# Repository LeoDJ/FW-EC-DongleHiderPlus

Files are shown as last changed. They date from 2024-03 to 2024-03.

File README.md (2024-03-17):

# DongleHider+ Framework Laptop Expansion Card

Want to use a Logitech Unifying Dongle (or similar) without having a dongle permanently sticking out and giving up on a precious expansion card slot?  

Now there's the `DongleHider+`!  

Simply (permanently) mount the dongle inside the card and still have an USB A port available!  

There even is room and solder pads for 1-2 additional dongles. Your imagination (and physics) are the only limits!

See also the [thread on Mastodon about the build process etc](https://chaos.social/@LeoDJ/112040053271880119).

<p float="left" style="display: flex; flex-wrap: wrap; align-items: center;">
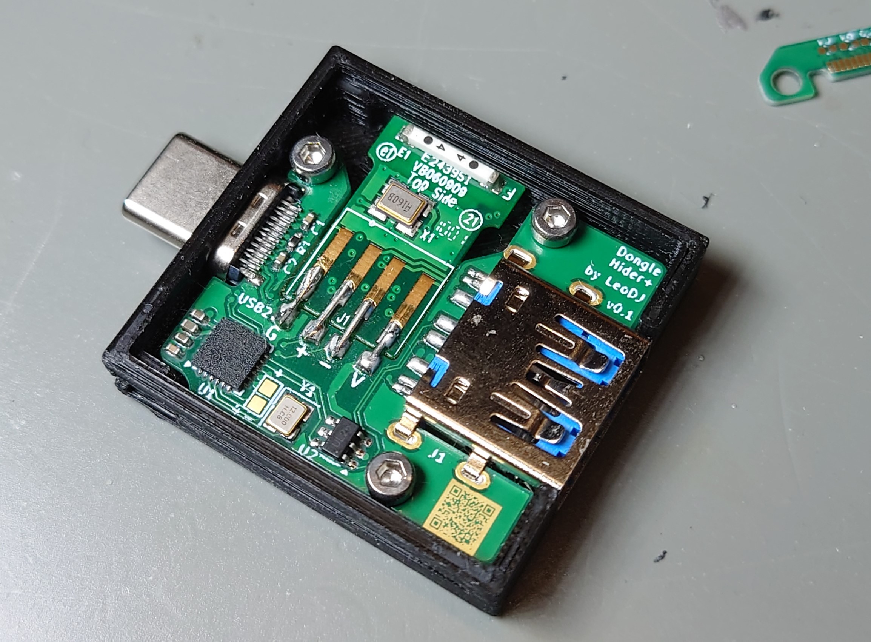
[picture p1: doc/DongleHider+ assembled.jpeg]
  &nbsp;
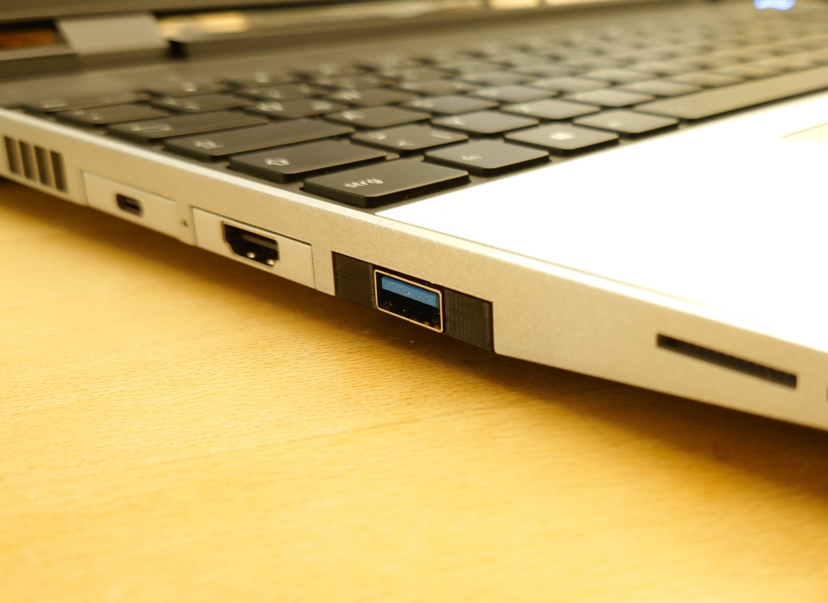
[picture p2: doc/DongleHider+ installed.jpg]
  
</p>

## Compatibility Notes

The expansion card was only tested on **Windows** and **AMD** Framework **13 and 16** laptops as of right now. There the following behaviour has been observed:
- With only a dongle active, the CH334 hub IC draws around 20mA. (In addition to the ~25mA of the Unifying dongle)
  - When nothing is connected to the hub, it goes to sleep and draws <1mA. (But this is seldomly the case with a dongle permanently attached to it :P )
- Despite earlier fears, the USB 3 "route-around-2.0-hub" topology doesn't seem to cause problems in the wild, except:
- When connected to a **USB4 capable expansion card slot** and an external **USB 3 device** is plugged in, the **internal dongle stops working**, but is still displayed as connected in Windows.
  - As soon as the USB 3 device gets unplugged, the internal dongle immediately begins to work again (probably without a re-enumeration).
  - USB 2 devices seem to work without a problem for the most part, although one of the tested USB thumb drives took a few re-plugs until it enumerated.
  - This behaviour is not seen on the other non-USB4-capable expansion card slots, there USB 3 devices work great alongside the internal dongle

It's currently unclear what the behaviour would be under Linux or on Intel laptops. <sup>[You can help expand this]</sup>

### Dongles

This project was aimed first and foremost at Logitech Unifying dongles. But you can check if your dongle would fit by disassembling it and checking its size against the CAD model (linked below).  
Keep in mind that there is more room under / above the PCB too. (I just made the cutout so a Unifying dongle PCB would fit neat-ish)

The Unifying dongles can be disassembled pretty easily:
|||
|---|---|
|  | **Gen 1:** <br>Carefully break off the plastic from the metal part using a pair of pliers. <br>(Can be glued back together, if needed)|
|  | **Gen 2:** <br>Slide flat screwdriver (or similar) between the metal and the orange plastic of the front of the USB a plug and carefully pry open the metal shell until it slides off. <br>[Youtube video](https://www.youtube.com/watch?v=NB5uVCrXxT8) |

## PCB
- [View the latest schematic and board view](https://kicanvas.org/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) thanks to KiCanvas.
- [Interactive HTML BOM](https://leodj.github.io/FW-EC-DongleHiderPlus/DongleHiderPlus_PCB/DongleHiderPlus_PCB.ibom.html)
- I've ordered the PCB and assembled it myself, but it should be able to be mostly assembled by PCBA services (like JLCPCB) too. The Gerber/BOM/CPL files are provided in the [PCB/jlcpcb/production_files/](DongleHiderPlus_PCB/jlcpcb/production_files/) folder.

<p float="left" style="display: flex; flex-wrap: wrap; align-items: center;">
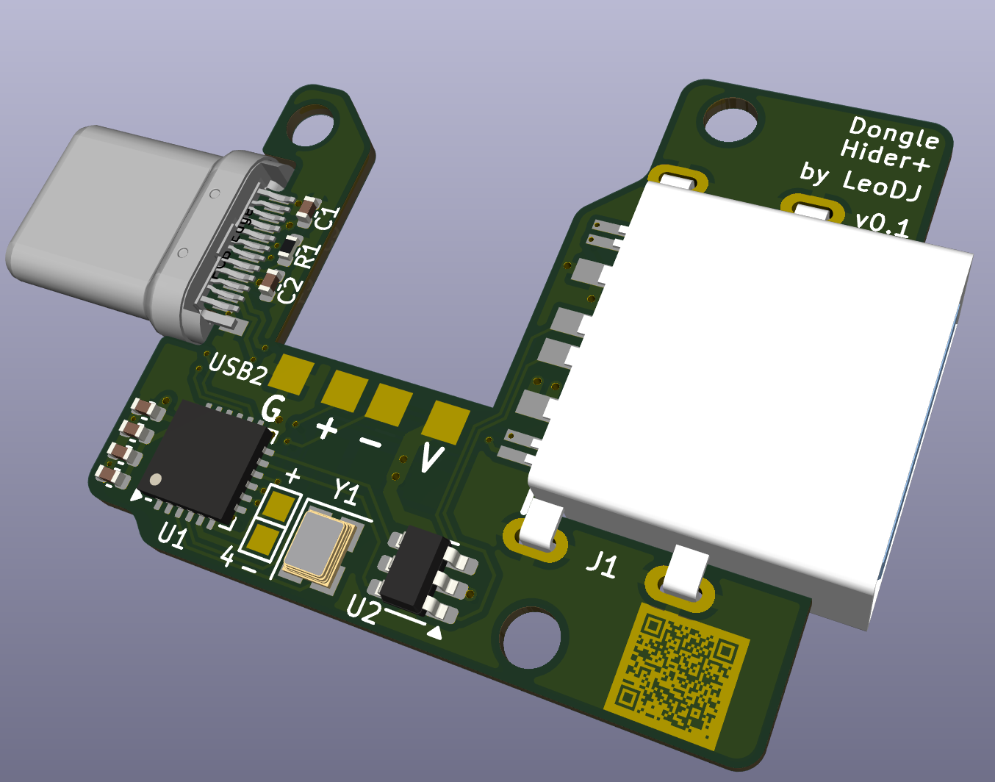
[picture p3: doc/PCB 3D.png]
  &nbsp;
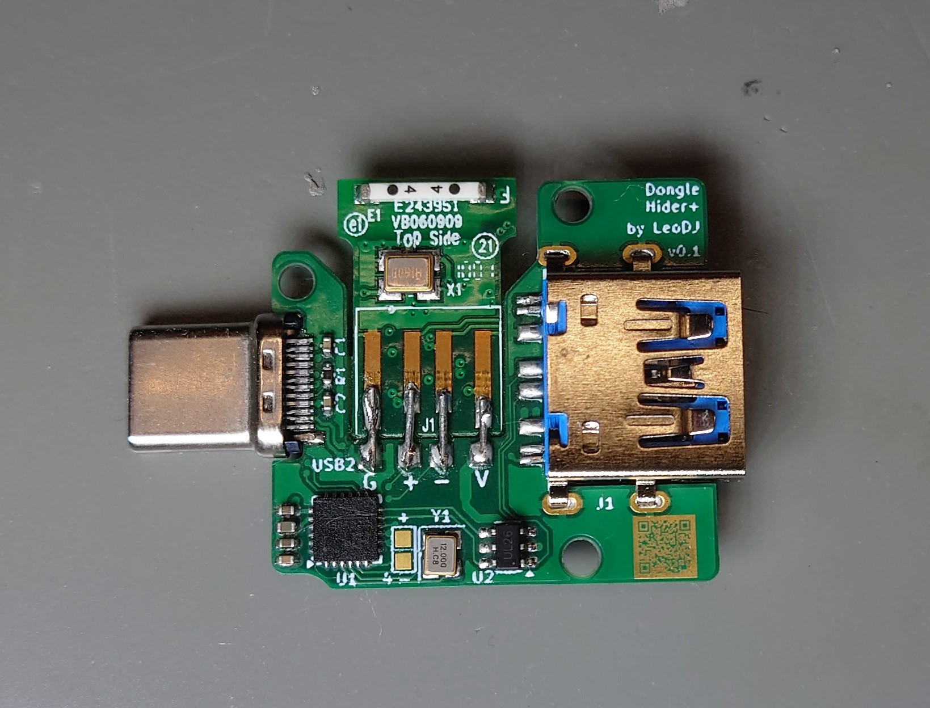
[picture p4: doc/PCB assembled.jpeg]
  
</p>

## Mechanical Design

- The [CAD model](https://cad.onshape.com/documents/ed6483270486e65268e8fd84/w/d29ba2284b9bcf206122f777/e/2459b9ec86bce6d6c9526a6b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) for the shell etc. was done in OnShape.
- The PCB is fastened to the case using 3 M2x3 self-tapping screws
- Simply print the .step file from the [Mechanical/](Mechanical/DongleHiderPlus_Shell.step) folder. I printed it lying down with 0.1mm layer height and supports (for the lip on the bottom). But standing vertically (on the USB-C hole side) should work too.

<p float="left" style="display: flex; flex-wrap: wrap; align-items: center;">
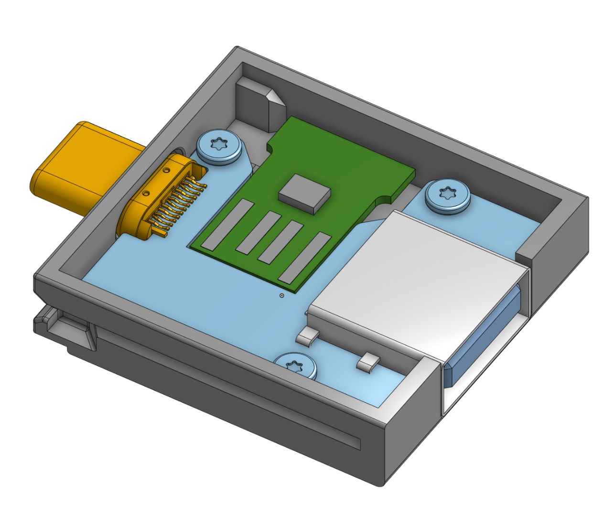
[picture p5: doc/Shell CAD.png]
  
</p>

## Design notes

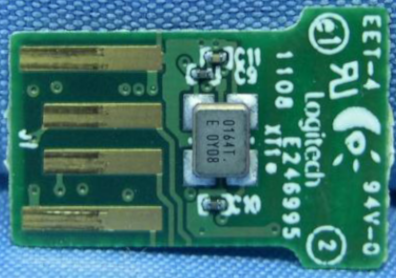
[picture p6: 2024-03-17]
doc/Unifying_PCB_top.png

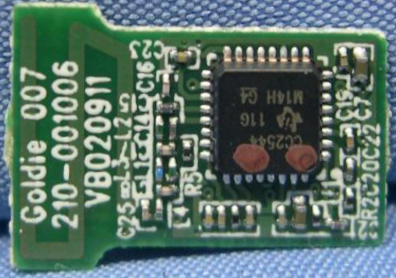
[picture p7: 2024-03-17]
doc/Unifying_PCB_bot.png

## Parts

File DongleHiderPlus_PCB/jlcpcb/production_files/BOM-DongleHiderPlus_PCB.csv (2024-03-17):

Comment | Designator | Footprint | LCSC
10n | C1,C2,C3,C4 | C_0402_1005Metric | C15195
10u | C7 | C_0402_1005Metric | C15525
5k1 | R1 | R_0402_1005Metric | C25905
USBLC6-2SC6 | U2 | SOT-23-6 | C2827654
12MHz | Y1 | Crystal_SMD_2520-4Pin_2.5x2.0mm | C284156
100n | C6 | C_0402_1005Metric | C307331
CH334F | U1 | QFN-24-1EP_4x4mm_P0.5mm_EP2.7x2.7mm | C5187527
1u | C5,C8 | C_0402_1005Metric | C52923
USB_C_Plug | P1 | USB_C_Plug_Molex_105444 | C561769
USB3_A | J1 | USB-A-SMD_HC-USB3.0-C345-P | C7501863

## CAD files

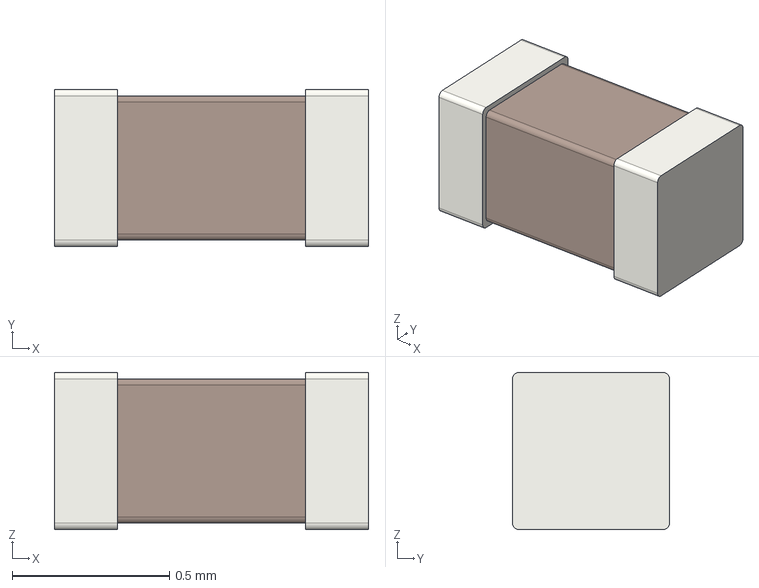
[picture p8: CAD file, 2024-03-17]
DongleHiderPlus_PCB/3dshapes/C_0402_1005Metric.step
1.00 x 0.5 x 0.5 mm

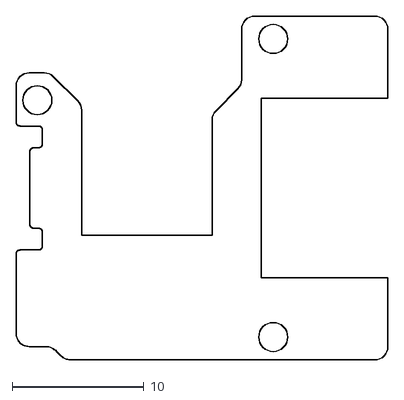
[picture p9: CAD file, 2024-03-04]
Mechanical/PCB Outline.dxf
28.2 x 26.1

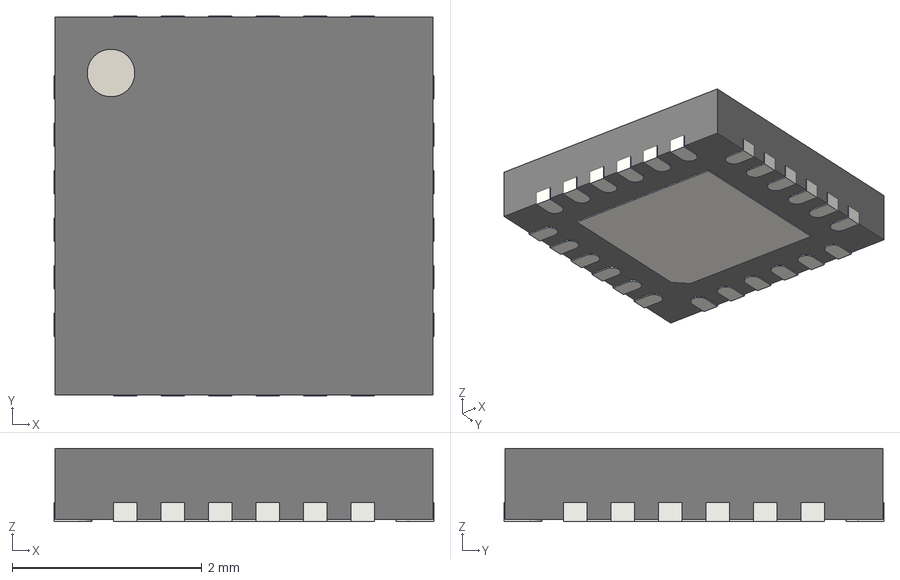
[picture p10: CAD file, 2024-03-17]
DongleHiderPlus_PCB/3dshapes/QFN-24-1EP_4x4mm_P0.5mm_EP2.6x2.6mm.step
4.00 x 4.00 x 0.77 mm

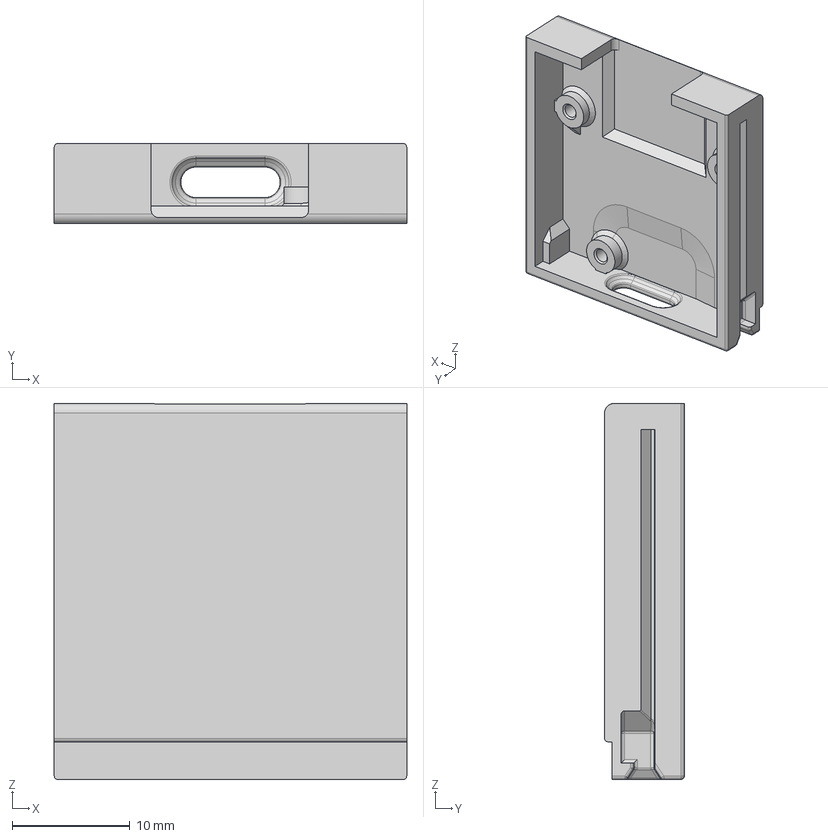
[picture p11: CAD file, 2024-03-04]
Mechanical/DongleHiderPlus_Shell.step
30.0 x 6.80 x 32.0 mm

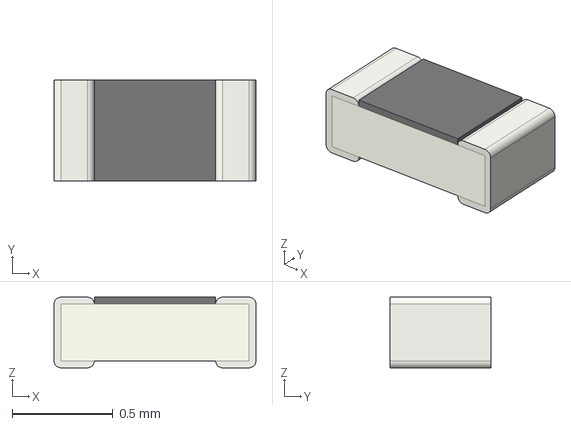
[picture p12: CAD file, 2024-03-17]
DongleHiderPlus_PCB/3dshapes/R_0402_1005Metric.step
1.00 x 0.5 x 0.35 mm

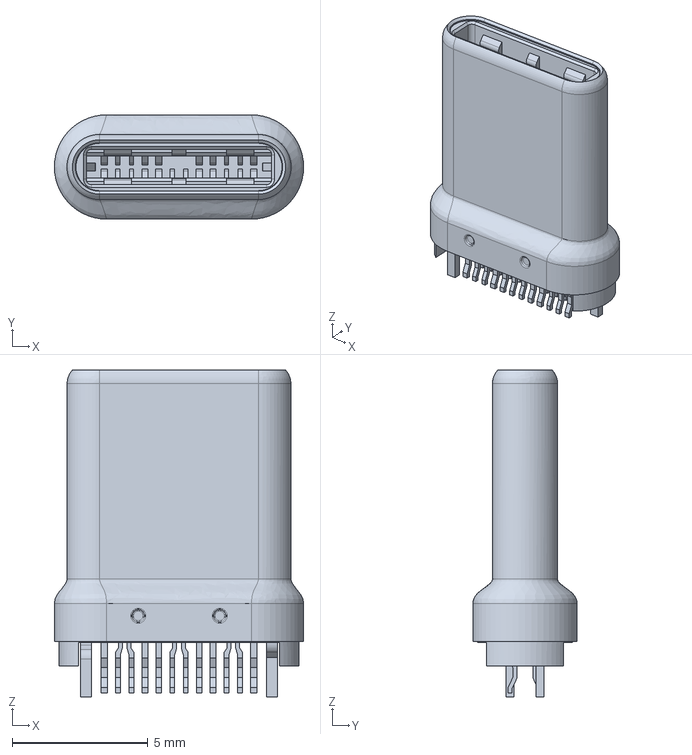
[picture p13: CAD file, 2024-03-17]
DongleHiderPlus_PCB/3dshapes/Molex_1054440011.stp
9.18 x 3.84 x 12.0 mm

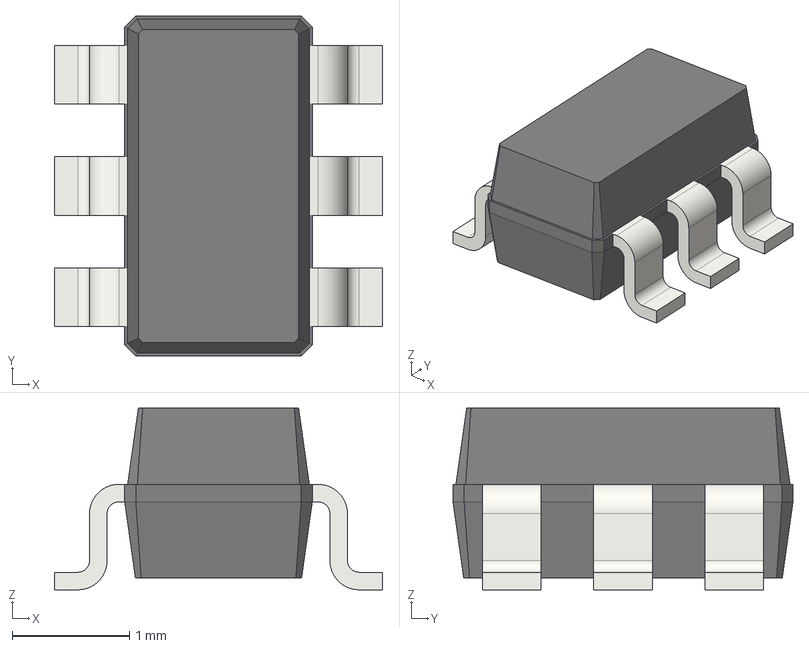
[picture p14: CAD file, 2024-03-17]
DongleHiderPlus_PCB/3dshapes/SOT-23-6.step
2.80 x 2.90 x 1.55 mm

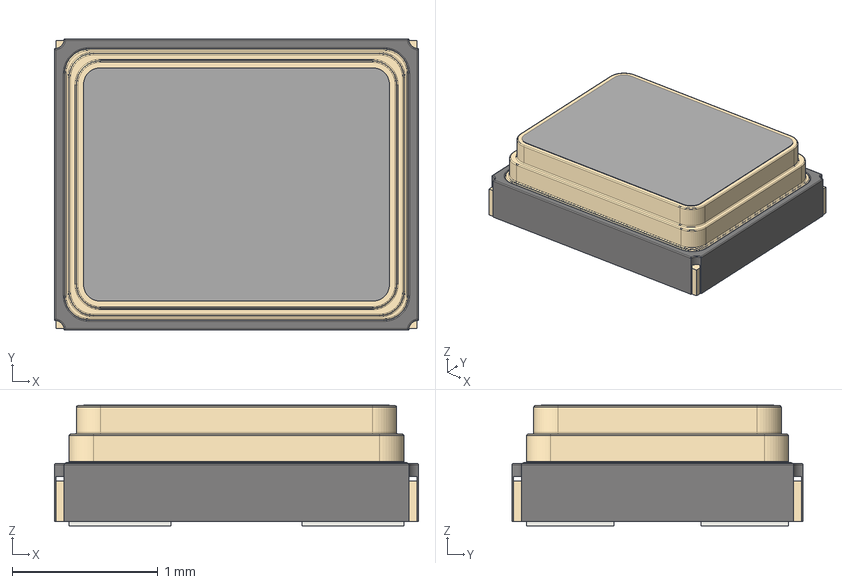
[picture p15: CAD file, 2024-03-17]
DongleHiderPlus_PCB/3dshapes/Crystal_SMD_2520-4Pin_2.5x2.0mm.step
2.50 x 2.00 x 0.83 mm

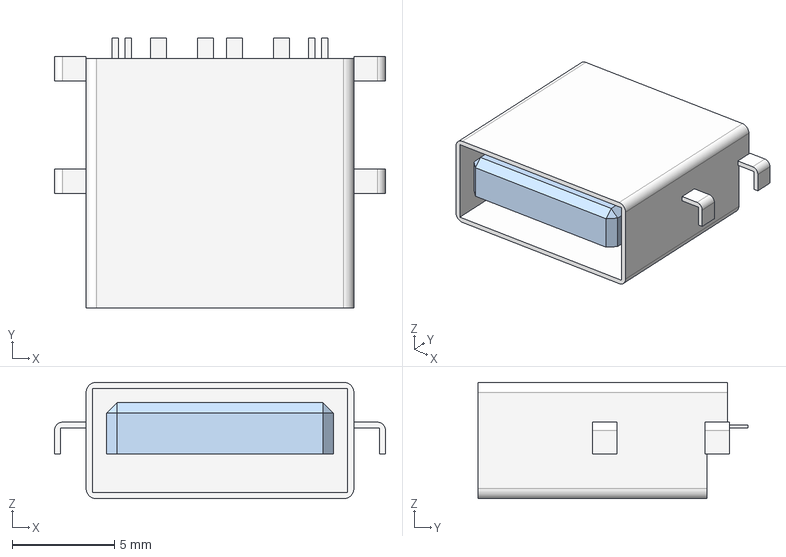
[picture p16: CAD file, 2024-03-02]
DongleHiderPlus_PCB/3dshapes/_HC-USB3.0-C345-P.step
16.2 x 13.2 x 5.70 mm

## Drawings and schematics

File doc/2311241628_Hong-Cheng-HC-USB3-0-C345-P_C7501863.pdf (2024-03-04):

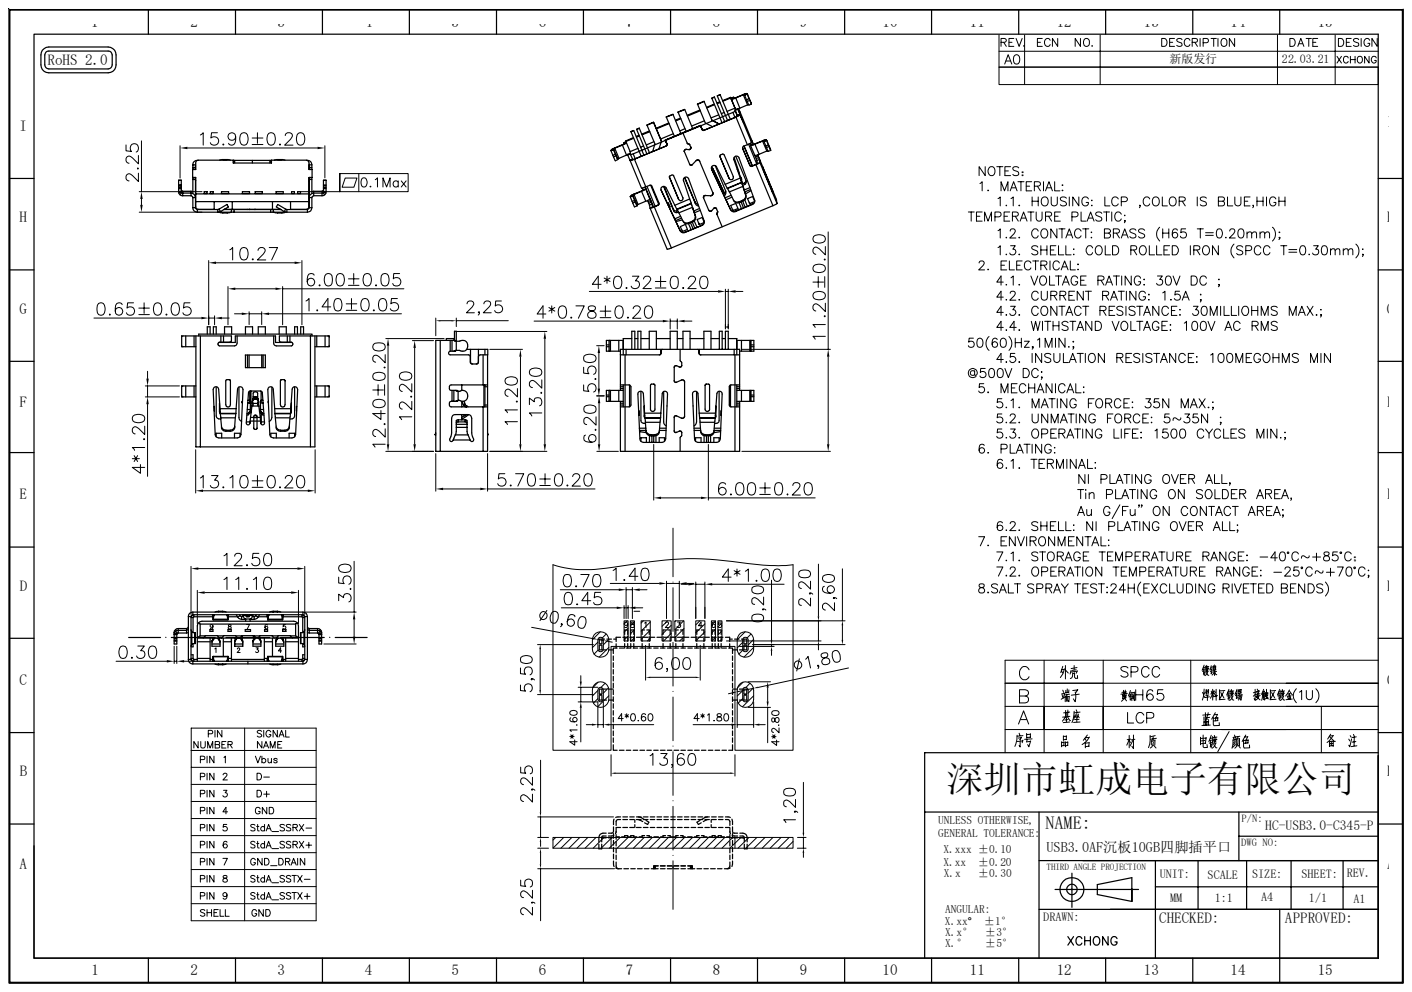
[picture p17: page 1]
RoHS 2.0; X.xxx ±0.10 X.xx ±0.20; ANGULAR:; DRAWN:; CHECKED:; APPROVED:; DWG NO:; USB3.0AF沉板10GB四脚插平口; 新版发行; 深圳市虹成电子有限公司; HC-USB3.0-C345-P

NAME: UNLESS OTHERWISE, GENERAL TOLERANCE:

THIRD ANGLE PROJECTION | UNIT: | SCALE | SIZE: | SHEET: | REV.

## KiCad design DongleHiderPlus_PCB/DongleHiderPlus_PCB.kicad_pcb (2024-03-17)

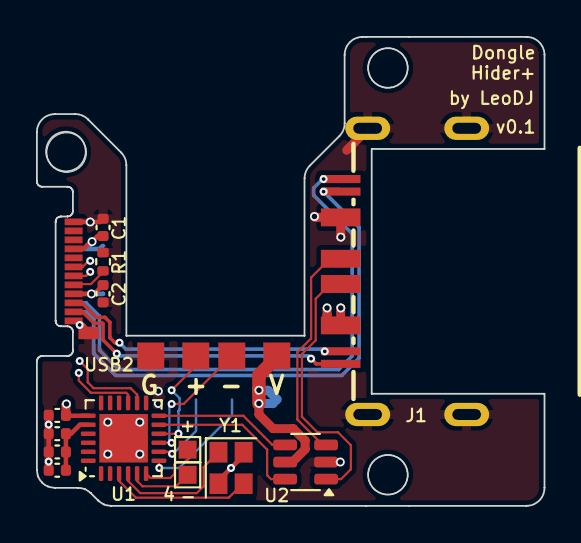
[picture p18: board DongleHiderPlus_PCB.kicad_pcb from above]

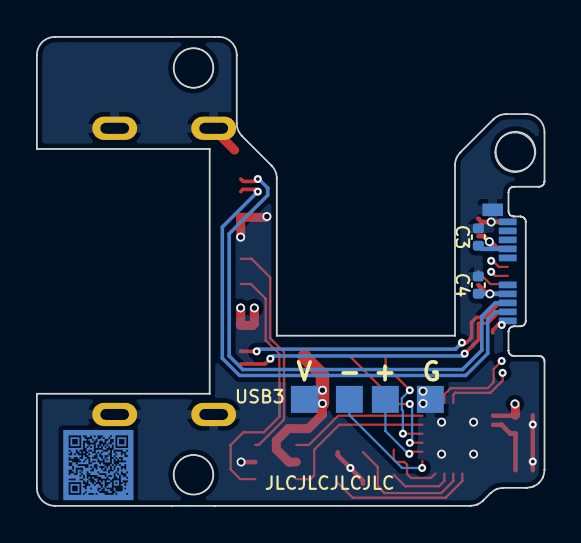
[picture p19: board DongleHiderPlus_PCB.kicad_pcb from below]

Board: 4 copper layers, 28.2 x 26.1 mm, 18 parts (3 on the bottom side), 22 nets.

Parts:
C1, C2, C3, C4: 10n; C_0402_1005Metric
C5, C8: 1u; C_0402_1005Metric
C6: 100n; C_0402_1005Metric
C7: 10u; C_0402_1005Metric
J1: USB3_A; USB-A-SMD_HC-USB3.0-C345-P
J4: D-4; TestPoint_Pad_1.0x1.0mm
J5: D+4; TestPoint_Pad_1.0x1.0mm
P1: USB_C_Plug; USB_C_Plug_Molex_105444
R1: 5k1; R_0402_1005Metric
U1: CH334F; QFN-24-1EP_4x4mm_P0.5mm_EP2.7x2.7mm
U2: USBLC6-2SC6; SOT-23-6
USB2, USB3: USB Dongle; USB_SolderPads
Y1: 12MHz; Crystal_SMD_2520-4Pin_2.5x2.0mm

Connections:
GND: C1.2, C2.2, C3.2, C4.2, C5.2, C6.2, C7.2, C8.2, J1.4 (GND), J1.10 (SHIELD), P1.A1 (GND), P1.A12 (GND), P1.B1 (GND), P1.B12 (GND), P1.S1 (SHIELD), R1.2, U1.25 (GND), U2.2 (GND), USB2.4, USB3.4, Y1.2, Y1.4
unnamed: J1.3 (D+), U2.3 (I/O2)
unnamed: J1.2 (D-), U2.1 (I/O1)
unnamed: J4.1, U1.5 (DM4-)
unnamed: J5.1, U1.6 (DP4+)
unnamed: P1.A5 (CC), R1.1
unnamed: P1.A6 (D+), U1.15 (DPU+)
unnamed: P1.A7 (D-), U1.14 (DMU-)
unnamed: U1.11 (DM1-), U2.6 (I/O1)
unnamed: U1.9 (DM2-), USB2.2
unnamed: U1.7 (DM3-), USB3.2
unnamed: U1.12 (DP1+), U2.4 (I/O2)
unnamed: U1.10 (DP2+), USB2.3
unnamed: U1.8 (DP3+), USB3.3
unnamed: C5.1, C6.1, C7.1, U1.20 (VDD33)
unnamed: U1.4 (XI), Y1.1
unnamed: U1.3 (XO), Y1.3
RX+: J1.6 (SSRX+), P1.B11 (RX1+)
RX-: J1.5 (SSRX-), P1.B10 (RX1-)
TX+: J1.9 (SSTX+), P1.A2 (TX1+)
TX-: J1.8 (SSTX-), P1.A3 (TX1-)
VBUS: C1.1, C2.1, C3.1, C4.1, C8.1, J1.1 (VBUS), P1.A4 (VBUS), P1.A9 (VBUS), P1.B4 (VBUS), P1.B9 (VBUS), U1.19 (V5), U2.5 (VBUS), USB2.1, USB3.1

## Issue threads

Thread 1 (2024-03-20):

Have you tried to not connect the USB2.0 pins to the external port?

wzqvip, 2024-03-20:
Have you tried to make the external port "usb3 only" or add a switch next to the port, which can 'cut off' the usb2 pins.

The problem could be caused by the management of USB4, I did not find any case about this.

LeoDJ, 2024-03-22:
Could be, that might work.
The best fix would be to just use a USB 3.0 hub IC, but I didn't want the added complexity, board space and cost.
Or just get rid of the USB 3 SS lanes altogether and define it as USB 2.0 only.

But honestly, for me personally, the compromise is absolutely fine as it is. My USB4 ports are pretty permanently occupied by USB-C expansion cards anyway, so I'll only use the DongleHider+ in the other slots.
(And even then I rarely use USB 3.0 devices with an A connectors)

But I can imagine some scenarios where the limitations would be more severe.

I think I'll close this for now, as I don't plan to make another revision in the near future, but if anyone else wants to take a crack at it, feel free to fork / modify it to suit your needs ^^

Closed 2024-03-22.

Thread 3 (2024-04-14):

Board Thickness - I believe it's incorrect

madeofpendletonwool, 2024-04-14:
Hi there,

Upon uploading the gerber file to JLCPCB the board thickness defaults to 1.6. I believe for the usb-c connector to work it would need to be 0.8 wouldn't it? Since the connector pins wraps around the board. Or is there someway to finagle the usb-c connector around the board that I'm not aware of?

Apologies if this isn't an actual issue? I certainly may just be understanding something incorrectly.

Thanks!

LeoDJ, 2024-04-15:
Yes, 0.8mm board thickness is correct, I've only documented the JLC settings in the release here: https://github.com/LeoDJ/FW-EC-DongleHiderPlus/releases/tag/v0.1

(afaik JLC always defaults to 1.6mm board thickness and doesn't read that information from the gerbers, in case it's even stored there)

madeofpendletonwool, 2024-04-15:
Ahh I gotcha. My apologies, I should have spotted that. Thanks!

Closed 2024-04-15.

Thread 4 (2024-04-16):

Successfully duplicated your work... runs fine on Pop OS Linux

davidsmoot, 2024-04-16:
Not really an issue but this seemed to be the best place to share.

I took all your generous work and reproduced a working board for my Framework 16 running Pop OS 22.04.

I used Osh Park for the board service, have two spare PCB's

I bought the parts from LCSC as you recommended.  Have enough parts for at least 5 units.

Bribed a coworker who is much better at soldering to do assembly.  Called in another favor with a coworker who printed the enclosures on a Formlabs printer.

Got lazy and skipped the fasteners because my 3D print is brittle and the fit was fantastic.

Have a Logitech dongle embedded as well as a cheap Ant+ dongle and both appear to work fine.

Thank you!

m10d, 2024-04-25:
> Have a Logitech dongle embedded as well as a cheap Ant+ dongle and both appear to work fine.

really appreciate the post @davidsmoot .  Do you have any comment on battery life?  sounds from the docs like a continuous 50mA draw is expected, but does this affect sleep?  As we saw with the gen1 hdmi adapters, sleep can be dramatically affected, and not in ways I at least am qualified to predict.

Thanks @LeoDJ for the work, this is super promising!!

davidsmoot, 2024-04-25:
To be honest, I don't know.  Have not run much on battery.  Have not noticed anything dramatic.  If there is a tool / test that I can run, I would be happy to.  Let me know

onas02, 2024-12-20:
Did you put both dongles in one unit? And if so how does it work on the pins at the back of the CPU aren't they the wrong way around?

davidsmoot, 2024-12-21:
Careful soldering.  You are correct about the reversed perspective.  Used
short jumpers to connect the correct pins.

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

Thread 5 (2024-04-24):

[Feature Request] Add a USB-C Port

juehv, 2024-04-24:
Hi,
I really love your DongleHider. I was wondering if it is possible to remove the screws, move the USB-A port closer to the edge and add another USB C port next to it (or maybe use two USB C ports).

For me, USB v2 speed would be enough on every port (for less complex PCB design), maybe this also fixes the issue with resetting the dongle on connecting a USB 3 device.

Would love to hear form you and see further improvements!

Cheers!

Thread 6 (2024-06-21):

JLCPCB Settings with Assembly?

EagleMitchell, 2024-06-21:
Greetings!  This is a fantastic project and I am very excited to give it a try.  I don't have good enough soldering skills to do the full PCB assembly so I am looking at ordering it through JLCPCB, however one question I am not sure on is do I need to select double-sided assembly or just single (top) side assembly for it to work?  This is my first venture in to custom PCB items so I am looking for some clarity on this.  here is a screenshot of what you get right after you upload the GERBER file, so I want to make sure I am making the correct selections for them to assemble it.  This would be helpful to have added to the README as well.

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

When I enable PCB assembly it gives me the option of Single-Top, Single-Bottom, or switch to PCBA for Double sided, but that significantly increases the price so I just want to get clarity on this.  Thanks!

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

triplo098, 2024-08-20:
Did you @EagleMitchell  ordered with top side as assembly side or abandoned this idea? I'm highly interested in ordering pre-assembled PCB (also lack of soldering skills) but I've encountered the same problem and I'm not sure if it's a good idea.

EagleMitchell, 2024-08-20:
> Did you @EagleMitchell ordered with top side as assembly side or abandoned this idea? I'm highly interested in ordering pre-assembled PCB (also lack of soldering skills) but I've encountered the same problem and I'm not sure if it's a good idea.

Since I never got an answer on here I didn't want to risk the money for a paper weight if it was wrong, so I haven't ordered anything yet.

m0zes, 2024-10-18:
Whatever you do, don't make my mistake. The edge connector for the usb c port is expecting a board thickness of 0.8mm. using the default thickness of 1.6mm will not work.

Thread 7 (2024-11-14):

USB 3 on USB 2 hub

JirikP, 2024-11-14:
Hi, love your work, but the USB 3 will not work correctly like that. Quick fix is to just do USB 2 type A connector on the outside and remove the extra USB lines or try to find suitable USB 3 hub and re-do your board. This is not a correct way and can create unexpected behaviour ei. wont work as USB 3 line.

LeoDJ, 2024-11-14:
Yes, this is known and quasi-intentional, see: https://github.com/LeoDJ/FW-EC-DongleHiderPlus?tab=readme-ov-file#compatibility-notes.

I didn't find a small enough USB 3 hub IC and wanted to try what would happen.

But feel free to improve the design for your requirements.

Closed 2024-11-14.

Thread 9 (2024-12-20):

Functionality on intel

onas02, 2024-12-20:
Just got my board and tried a few things. Haven't soldered the adapter into it yet, but the USB itself works great for now. I'm going to test the described cases on the USB4-Connection where some stuff doesn't work the next days and gonna post an update about that. If you have anything I could try feel free to reach out.

onas02, 2024-12-25:
Now that I had a little time it seems like the USB and the adapter work very well. I can plug in any device and it works. Don't have many 3.0 devices but haven't noticed an issue with the USB Storage.
One very important thing though! Something doesn't work right. After a while leaving the adapter plugged in, the laptop doesn't turn on. An error code is displayed through the debug LED and that's it. After unplugging the adapter it turns on again. Does anybody have an idea, why that could be?
Nearly had a Heartattack because of it. My laptop is just outside the warranty window and wouldn't turn on, on Christmas morning.

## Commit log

2024-03-02 rough PCB layout done
    [DongleHider+_PCB.kicad_pcb, DongleHider+_PCB.kicad_sch]
2024-03-02 final mechanical & silkscreen touches
    [DongleHider+_PCB.kicad_pcb, DongleHider+_PCB.kicad_sch]
2024-03-04 rename KiCad project
    [DongleHiderPlus_PCB.kicad_pcb, DongleHiderPlus_PCB.kicad_sch]
2024-03-04 add production files for rev 0.1
    [BOM-DongleHiderPlus_PCB.csv, DongleHiderPlus_PCB.kicad_pcb, DongleHiderPlus_Shell.step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]
2024-03-05 increase via size to make JLC happy
    [DongleHiderPlus_PCB.kicad_pcb]
2024-03-05 add gerber
2024-03-16 add HTML BOM
2024-03-17 add/archive 3D models
    [C_0402_1005Metric.step, Crystal_SMD_2520-4Pin_2.5x2.0mm.step, DongleHiderPlus_PCB.kicad_pcb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]
2024-03-17 update BOM / CPL
    [BOM-DongleHiderPlus_PCB.csv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]

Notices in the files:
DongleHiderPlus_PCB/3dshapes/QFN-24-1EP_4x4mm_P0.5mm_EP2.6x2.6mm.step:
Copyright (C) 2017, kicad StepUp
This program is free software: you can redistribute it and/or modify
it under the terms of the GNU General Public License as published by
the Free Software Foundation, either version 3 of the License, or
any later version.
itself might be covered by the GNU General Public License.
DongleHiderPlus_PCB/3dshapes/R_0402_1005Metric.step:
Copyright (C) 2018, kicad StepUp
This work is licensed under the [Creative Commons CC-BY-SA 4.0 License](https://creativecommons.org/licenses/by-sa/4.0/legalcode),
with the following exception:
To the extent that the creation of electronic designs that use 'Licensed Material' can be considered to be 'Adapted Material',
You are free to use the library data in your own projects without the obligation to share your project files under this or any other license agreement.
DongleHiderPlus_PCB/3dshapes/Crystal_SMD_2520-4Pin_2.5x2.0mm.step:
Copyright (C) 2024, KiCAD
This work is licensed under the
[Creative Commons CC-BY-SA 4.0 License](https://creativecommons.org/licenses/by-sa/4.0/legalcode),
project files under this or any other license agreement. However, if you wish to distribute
